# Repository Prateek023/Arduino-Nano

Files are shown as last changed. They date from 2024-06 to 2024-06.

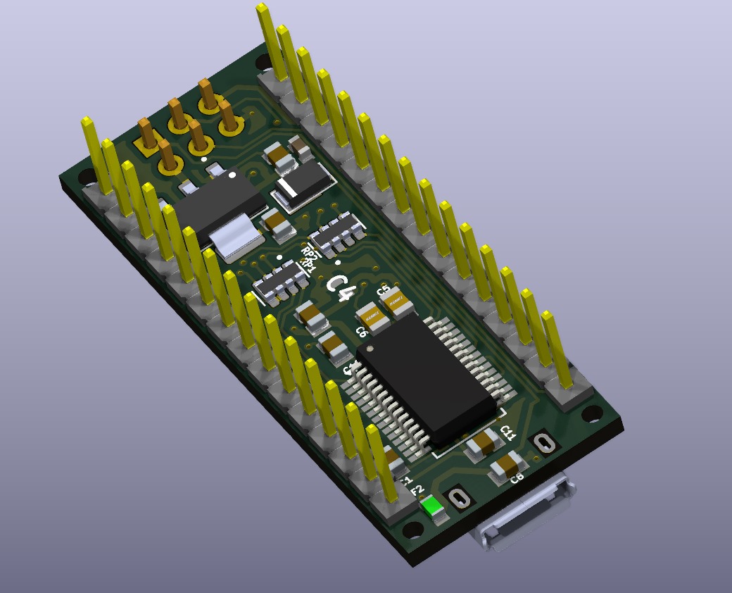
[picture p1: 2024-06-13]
arduino nano/Images/back 3d.jpg

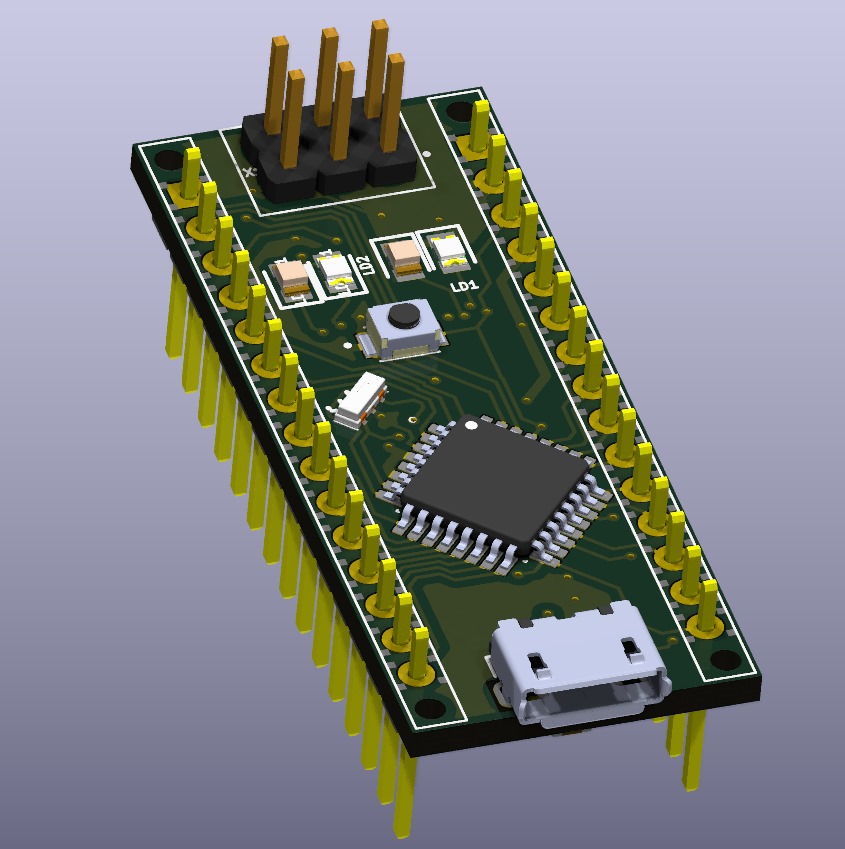
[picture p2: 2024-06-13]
arduino nano/Images/front 3d.jpg

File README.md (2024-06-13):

# Custom-Arduino-Nano
This project revolves around a custom-designed Arduino Nano, engineered to meet specific needs. Whether it's for a particular application, compactness, or additional features, this custom Arduino Nano offers a tailored solution for your project requirements.
## Hardware Setup
Assemble the custom-designed Arduino Nano board according to the provided schematic and layout diagrams. Ensure all components are soldered correctly and connections are secure.
## Contributing
Contributions to the Custom Arduino Nano project are welcome! If you'd like to contribute, please follow these guidelines:

  1) Fork the repository and create a new branch for your feature or bug fix.
  2) Make your changes and ensure that the code follows the project's coding conventions.
  3) Test your changes thoroughly.
  4) Submit a pull request with a clear description of your changes and their purpose.

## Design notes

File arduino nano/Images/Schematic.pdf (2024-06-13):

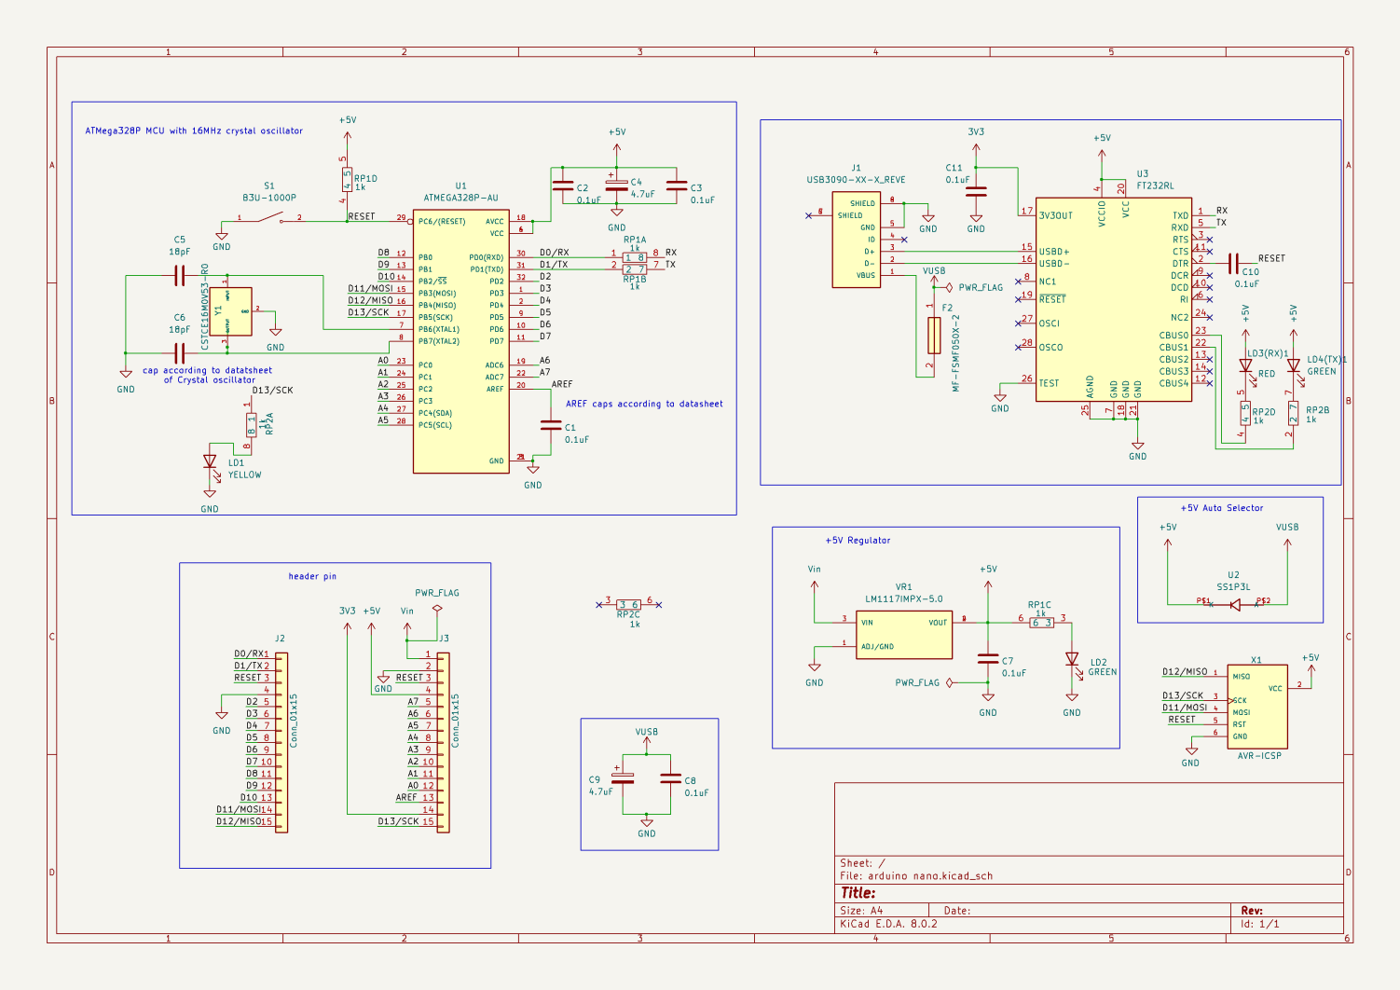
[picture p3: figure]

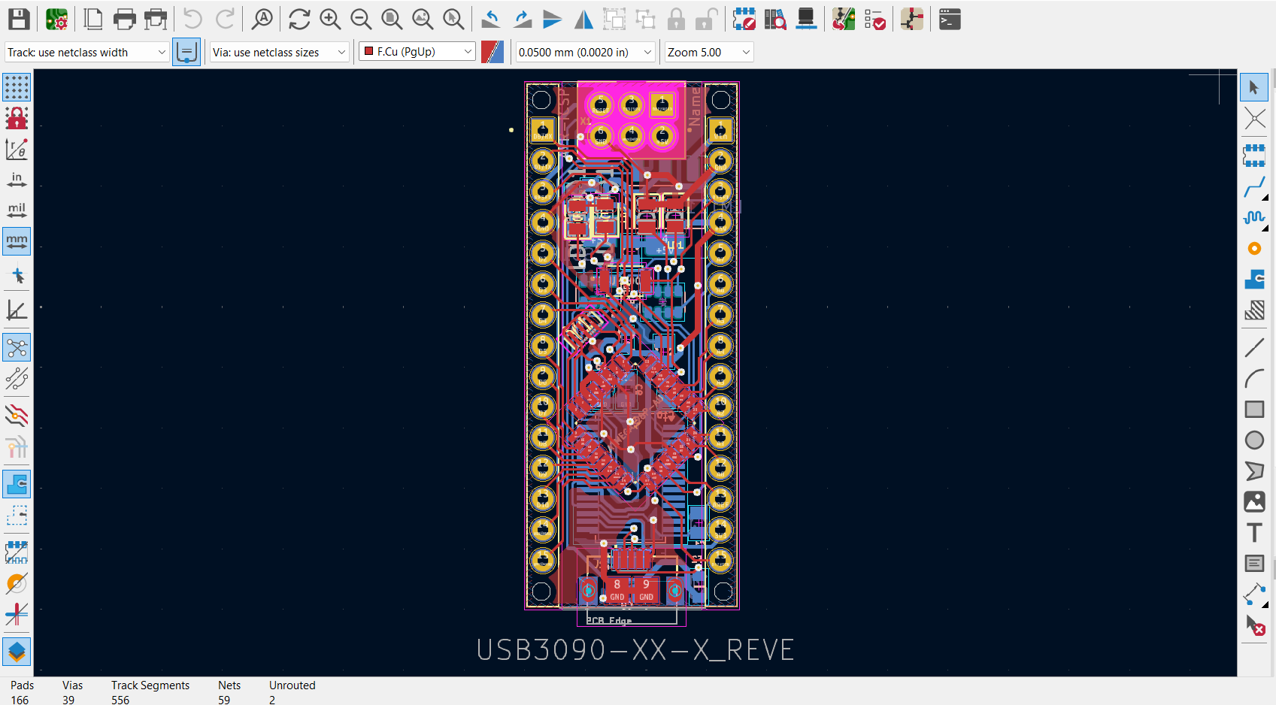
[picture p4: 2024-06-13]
arduino nano/Images/Layout.png

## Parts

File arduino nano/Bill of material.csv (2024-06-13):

Reference | Value | Datasheet | Footprint | Qty | DNP
C1,C2,C3,C7,C8,C10,C11 | 0.1uF | https://www.mouser.in/datasheet/2/40/KGM_X7R-3223212.pdf | cap_0.1uF:CAPC2012X94N | 7
C4,C9 | 4.7uF | https://www.mouser.in/datasheet/2/281/murata_03052018_GRM_Series_1-1310166.pdf | cap_4.7uF_16V:CAPC1608X90N | 2
C5,C6 | 18pF | https://www.mouser.in/datasheet/2/447/KEM_C1003_C0G_SMD-3316496.pdf | cap_18pF:C0805 | 2
F2 | MF-FSMF050X-2 | https://www.mouser.in/datasheet/2/54/mffsmf-777670.pdf | KiCad:FUSC1608X100N | 1
J1 | USB3090-XX-X_REVE | https://www.snapeda.com/parts/USB3090-30-A/Global%20Connector%20Technology/datasheet/ | USB3090-XX-X_REVE:GCT_USB3090-XX-X_REVE | 1
J2,J3 | Conn_01x15 | https://cdn.amphenol-cs.com/media/wysiwyg/files/documentation/datasheet/boardwiretoboard/bwb_bergstik.pdf | my_Library:header_pin1x15 | 2
LD1 | YELLOW | ~ | LED_orange:LEDC2012X50N | 1
LD2,LD4(TX)1 | GREEN | https://www.mouser.in/datasheet/2/216/APHCM2012CGCK_F01-34366.pdf | -- mixed values -- | 2
LD3(RX)1 | RED | https://www.mouser.in/datasheet/2/216/APT2012SRCPRV-56885.pdf | LED_red:LEDC2012X85N | 1
RP1,RP2 | 1k | https://www.yageo.com/upload/media/product/app/datasheet/rchip/pyu-yc_tc_group_51_rohs_l.pdf | YC164_JR_071KL:RESCAXE80P320X160X70-8N | 2
S1 | B3U-1000P | https://omronfs.omron.com/en_US/ecb/products/pdf/en-b3u.pdf | B3U_1000P:SW_B3U-1000P | 1
U1 | ATMEGA328P-AU | https://ww1.microchip.com/downloads/aemDocuments/documents/MCU08/ProductDocuments/DataSheets/ATmega48A-PA-88A-PA-168A-PA-328-P-DS-DS40002061B.pdf | ATMEGA328P-AU:QFP80P900X900X120-32N | 1
U2 | SS1P3L | https://www.vishay.com/docs/88915/ss1p3l.pdf | SS1P3L:DO220AAL | 1
U3 | FT232RL | https://www.ftdichip.com/Support/Documents/DataSheets/ICs/DS_FT232R.pdf | Package_SO:SSOP-28_5.3x10.2mm_P0.65mm | 1
VR1 | LM1117IMPX-5.0 | https://www.ti.com/lit/ds/symlink/lm1117.pdf?HQS=dis-mous-null-mousermode-dsf-pf-null-wwe&DCM=yes&distId=26 | LM1117IMPX-5.0:SOT230P700X180-4N | 1
X1 | AVR-ICSP |  | AVR-ICSP:ICSP-2X03-2.54 | 1
Y1 | CSTCE16M0V53-R0 | https://www.murata.com/en-sg/products/productdetail?partno=CSTCE16M0V53-R0 | crystal_3Terminal:CSTCE16M0V53R0 | 1

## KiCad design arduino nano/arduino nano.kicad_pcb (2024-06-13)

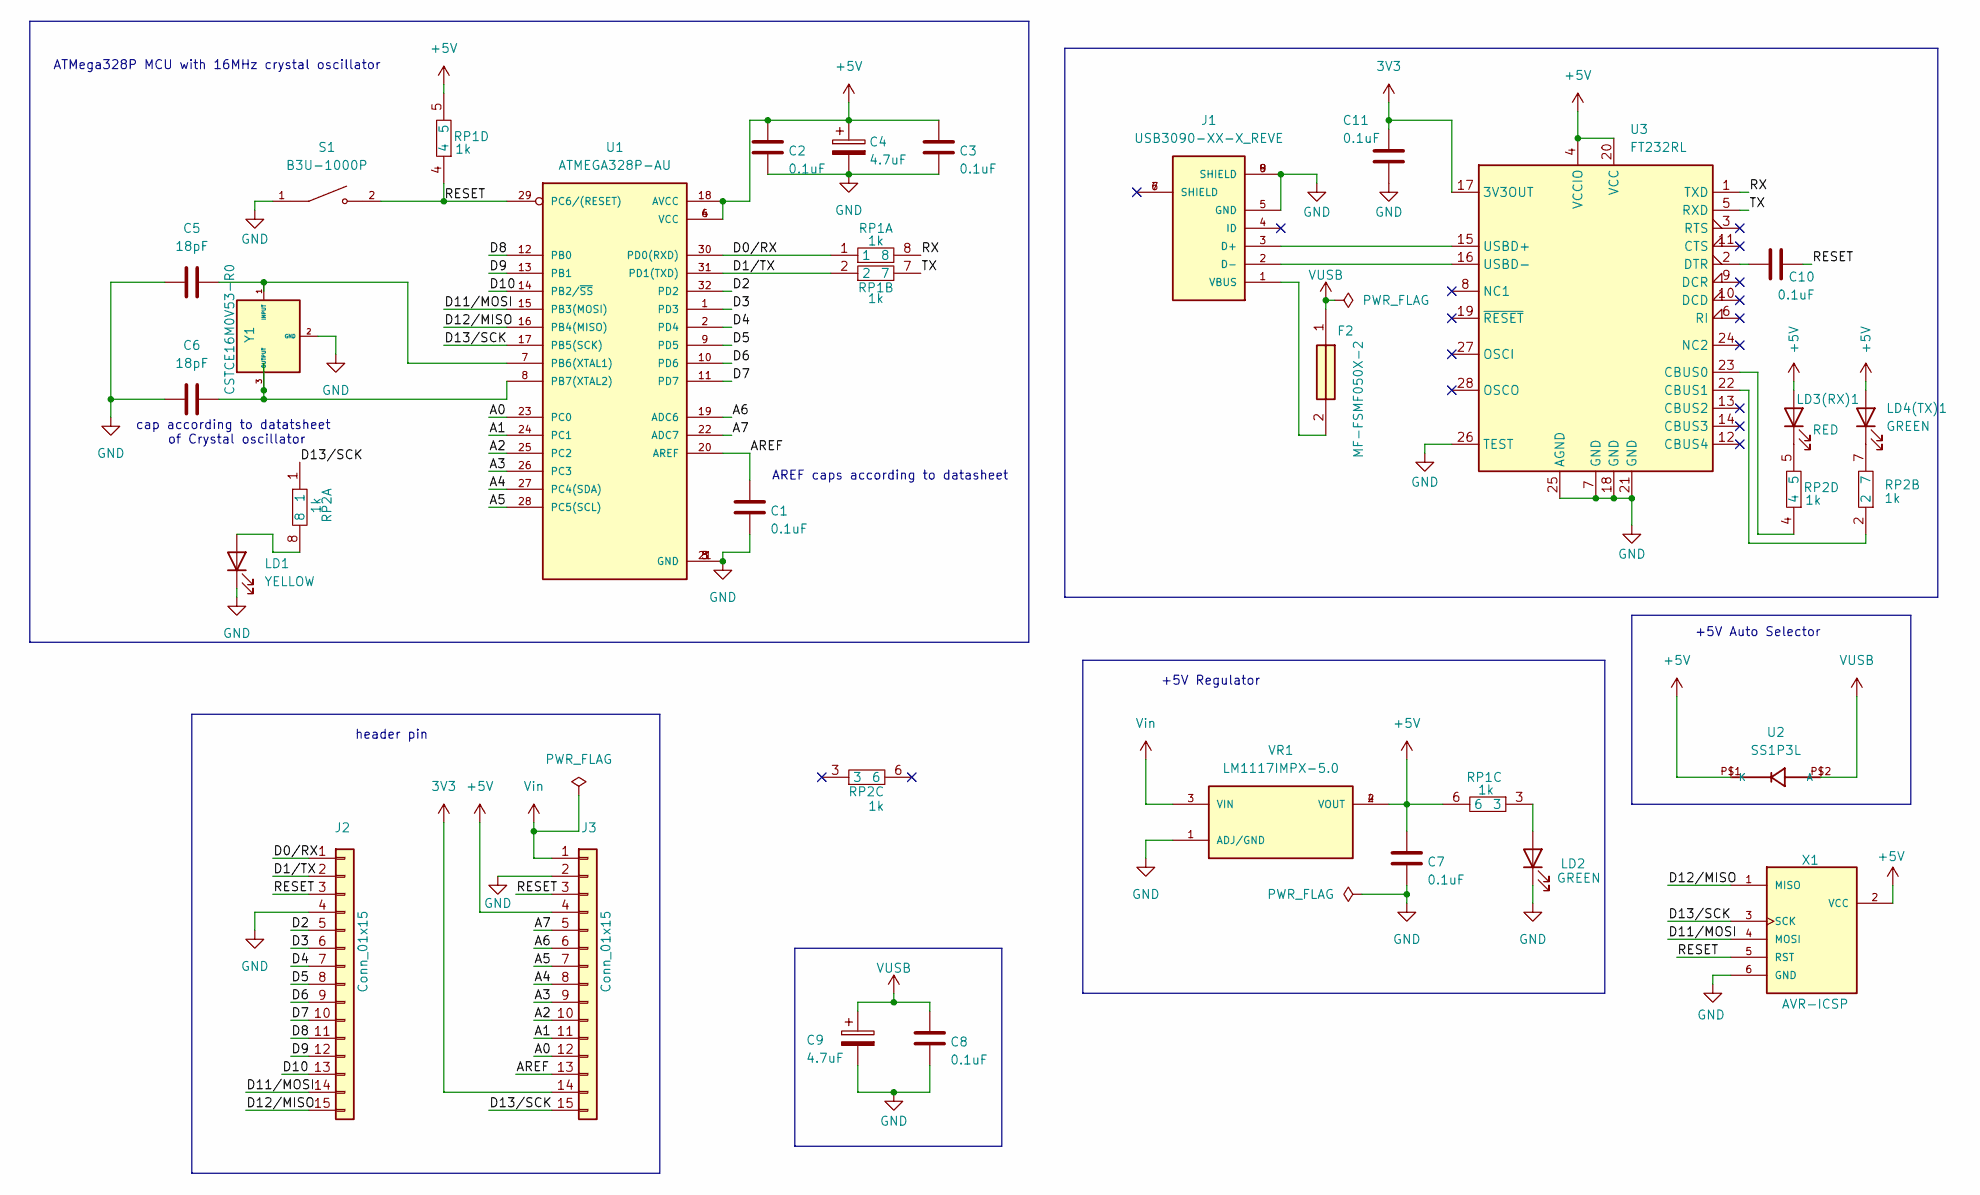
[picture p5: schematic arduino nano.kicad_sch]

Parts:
C1, C2, C3, C7, C8, C10, C11: 0.1uF; CAPC2012X94N
C4, C9: 4.7uF; CAPC1608X90N
C5, C6: 18pF; C0805
F2: MF-FSMF050X-2; FUSC1608X100N; Mouser Part Number 652-MFFSMF050X-2
J1: USB3090-XX-X_REVE; GCT_USB3090-XX-X_REVE
J2, J3: Conn_01x15; header_pin1x15
LD1: YELLOW; LEDC2012X50N
LD2: GREEN; LEDC2012X85N
LD3(RX)1: RED; LEDC2012X85N
LD4(TX)1: GREEN; LEDC2012X50N
RP1, RP2: 1k; RESCAXE80P320X160X70-8N
S1: B3U-1000P; SW_B3U-1000P
U1: ATMEGA328P-AU; QFP80P900X900X120-32N; PARTREV 8271A
U2: SS1P3L; DO220AAL
U3: FT232RL; SSOP-28_5.3x10.2mm_P0.65mm
VR1: LM1117IMPX-5.0; SOT230P700X180-4N; PARTREV O
X1: AVR-ICSP; ICSP-2X03-2.54
Y1: CSTCE16M0V53-R0; CSTCE16M0V53R0; Mouser Part Number 81-CSTCE16M0V53-R0

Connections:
3V3: C11.1, J3.14, U3.17 (3V3OUT)
+5V: C2.1, C3.1, C4.1, C7.1, J3.4, LD3(RX)1.2 (A), LD4(TX)1.2 (A), RP1.5, RP1.6, U1.4 (VCC), U1.6 (VCC), U1.18 (AVCC), U2.P$1 (K), U3.4 (VCCIO), U3.20 (VCC), VR1.2 (VOUT), VR1.4 (VOUT), X1.2 (VCC)
/A0: J3.12, U1.23 (PC0)
/A1: J3.11, U1.24 (PC1)
/A2: J3.10, U1.25 (PC2)
/A3: J3.9, U1.26 (PC3)
/A4: J3.8, U1.27 (PC4(SDA))
/A5: J3.7, U1.28 (PC5(SCL))
/A6: J3.6, U1.19 (ADC6)
/A7: J3.5, U1.22 (ADC7)
/AREF: C1.1, J3.13, U1.20 (AREF)
/D0/RX: J2.1, RP1.1, U1.30 (PD0(RXD))
/D1/TX: J2.2, RP1.2, U1.31 (PD1(TXD))
/D2: J2.5, U1.32 (PD2)
/D3: J2.6, U1.1 (PD3)
/D4: J2.7, U1.2 (PD4)
/D5: J2.8, U1.9 (PD5)
/D6: J2.9, U1.10 (PD6)
/D7: J2.10, U1.11 (PD7)
/D8: J2.11, U1.12 (PB0)
/D9: J2.12, U1.13 (PB1)
/D10: J2.13, U1.14 (PB2/~SS)
/D11/MOSI: J2.14, U1.15 (PB3(MOSI)), X1.4 (MOSI)
/D12/MISO: J2.15, U1.16 (PB4(MISO)), X1.1 (MISO)
/D13/SCK: J3.15, RP2.1, U1.17 (PB5(SCK)), X1.3 (SCK)
/RESET: C10.2, J2.3, J3.3, RP1.4, S1.2, U1.29 (PC6/(RESET)), X1.5 (RST)
/RX: RP1.8, U3.1 (TXD)
/TX: RP1.7, U3.5 (RXD)
GND: C1.2, C2.2, C3.2, C4.2, C5.1, C6.1, C7.2, C8.2, C9.2, C11.2, J1.5 (GND), J1.8 (SHIELD), J1.9 (SHIELD), J2.4, J3.2, LD1.1 (K), LD2.1 (K), S1.1, U1.3 (GND), U1.5 (GND), U1.21 (GND), U3.7 (GND), U3.18 (GND), U3.21 (GND), U3.25 (AGND), U3.26 (TEST), VR1.1 (ADJ/GND), X1.6 (GND), Y1.2 (GND)
unnamed: J1.3 (D+), U3.15 (USBD+)
unnamed: J1.2 (D-), U3.16 (USBD-)
unnamed: F2.2, J1.1 (VBUS)
unnamed: LD1.2 (A), RP2.8
unnamed: LD2.2 (A), RP1.3
unnamed: LD3(RX)1.1 (K), RP2.5
unnamed: LD4(TX)1.1 (K), RP2.7
unnamed: C5.2, U1.7 (PB6(XTAL1)), Y1.1 (INPUT)
unnamed: C6.2, U1.8 (PB7(XTAL2)), Y1.3 (OUTPUT)
unnamed: RP2.4, U3.23 (CBUS0)
unnamed: RP2.2, U3.22 (CBUS1)
unnamed: C10.1, U3.2 (DTR)
VUSB: C8.1, C9.1, F2.1, U2.P$2 (A)
Vin: J3.1, VR1.3 (VIN)

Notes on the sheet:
ATMega328P MCU with 16MHz crystal oscillator
AREF caps according to datasheet
+5V Auto Selector
cap according to datatsheet of Crystal oscillator
+5V Regulator
header pin

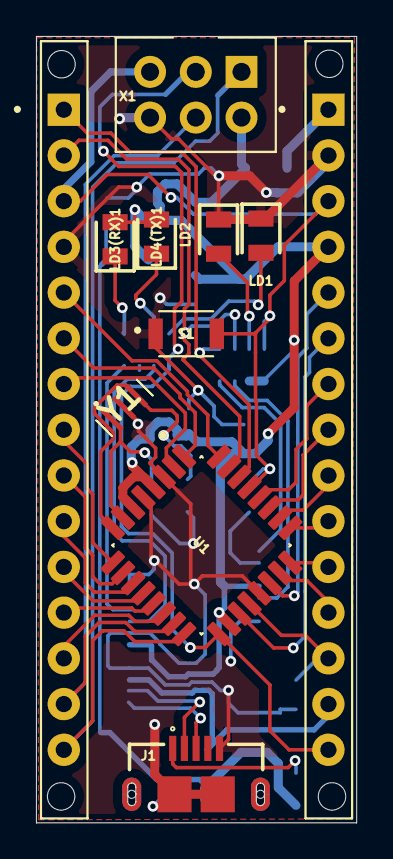
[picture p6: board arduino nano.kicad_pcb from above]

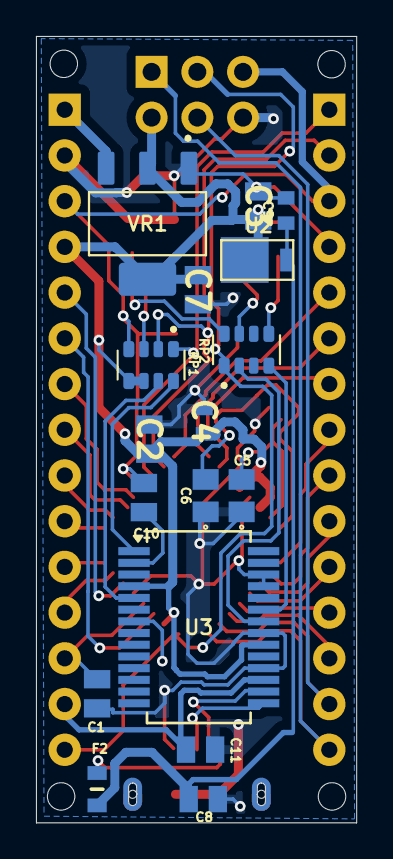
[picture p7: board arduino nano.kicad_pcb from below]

Board: 2 copper layers, 17.8 x 43.7 mm, 28 parts (17 on the bottom side), 43 nets.
